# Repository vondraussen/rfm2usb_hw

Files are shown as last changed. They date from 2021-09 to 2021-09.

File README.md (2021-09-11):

# RFM2USB Hardware
USB to RFM69 board made with Kicad. Uses a STM32L151 microcontroller.
Firmware repo is [here](https://github.com/vondraussen/rfm2usb).

## Schematic
schematic
## Board



# Tools
```bash
pip install pcbdraw
```

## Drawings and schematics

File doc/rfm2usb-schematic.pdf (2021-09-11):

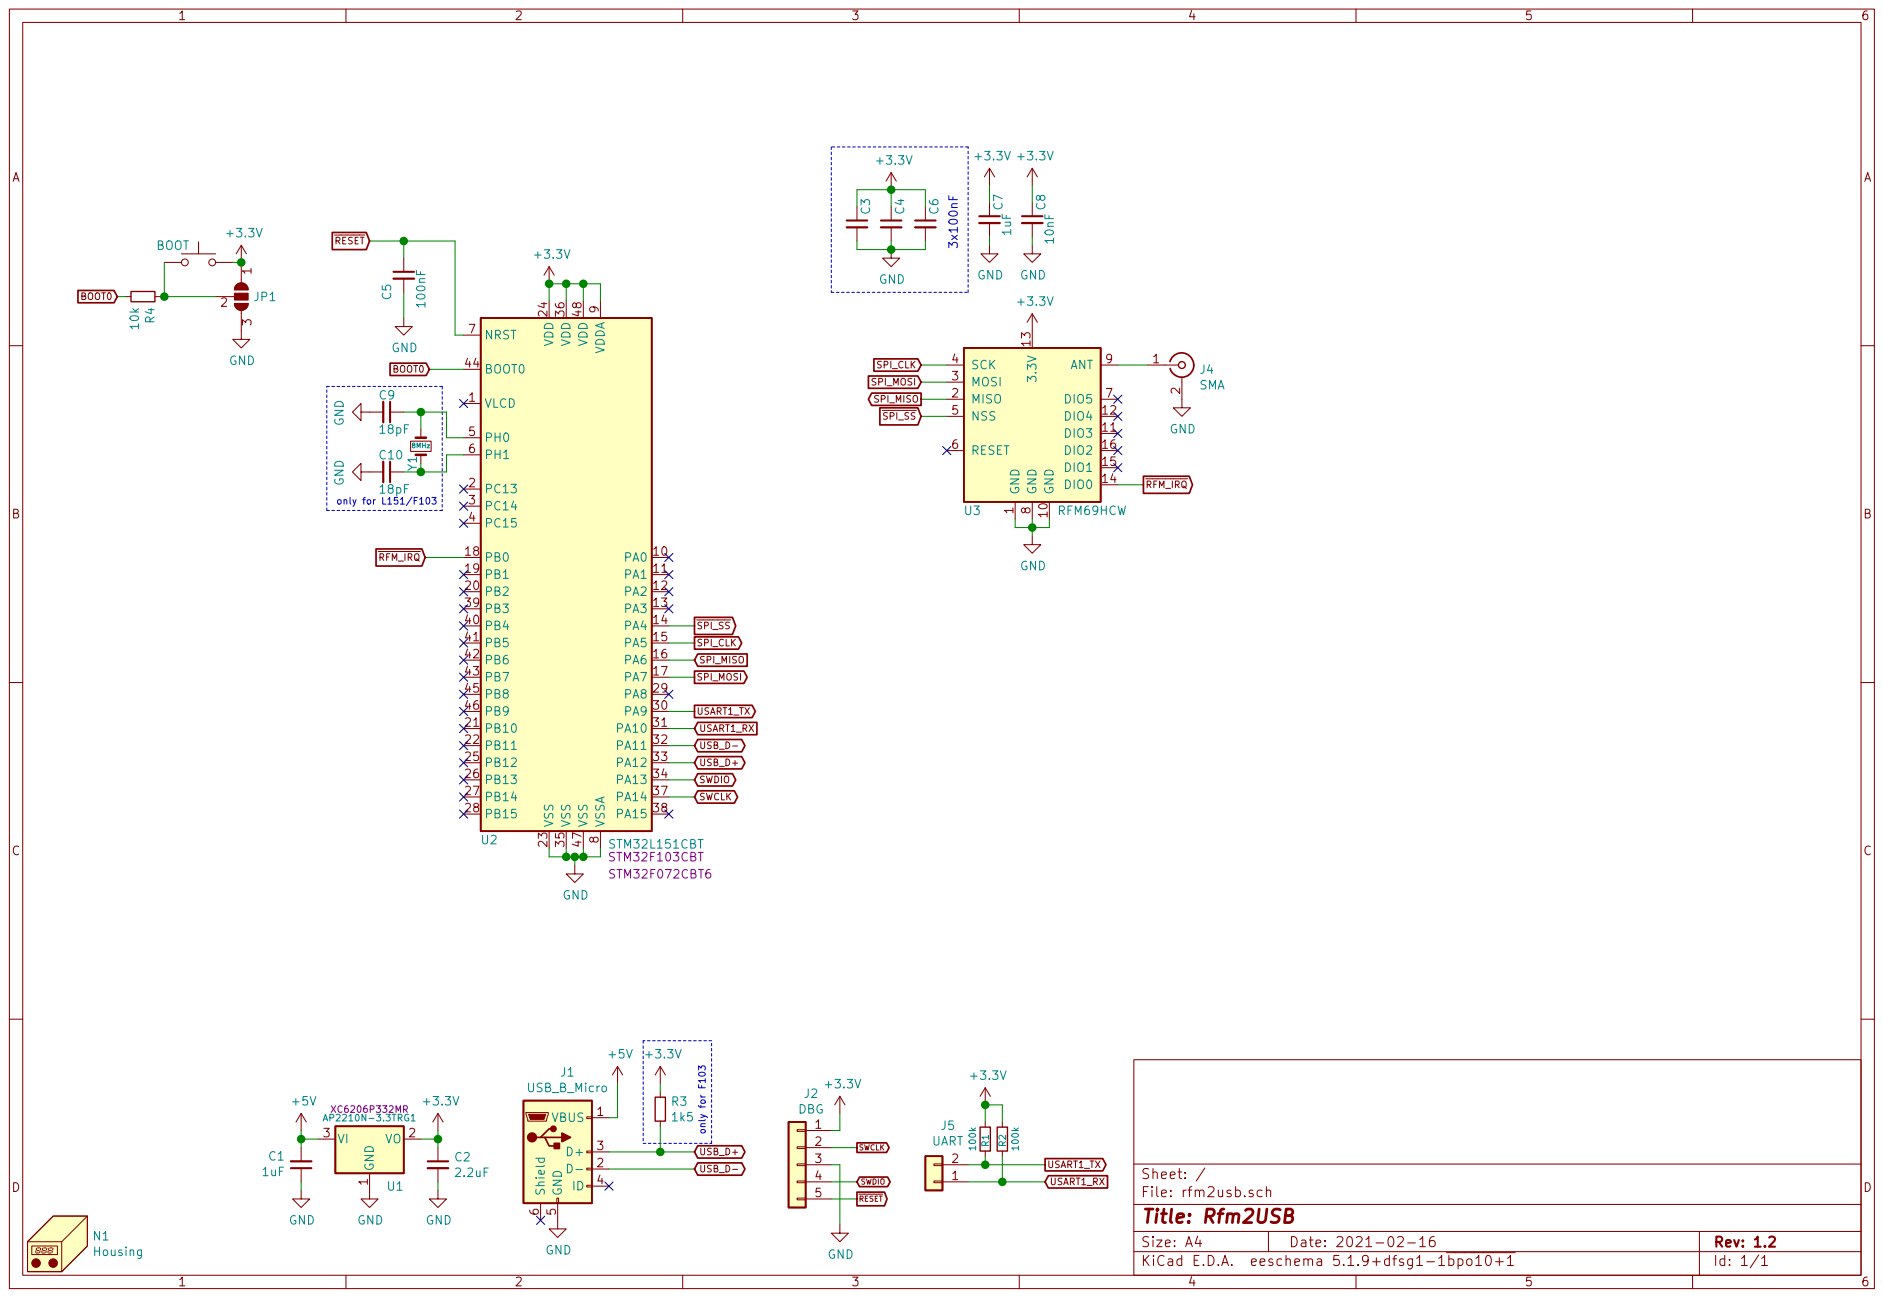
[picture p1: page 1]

9 VLCD 1 VSS 23 VSS 35 VSS 47 VSSA U2 8STM32L151CBT STM32F103CBT STM32F072CBT6 GND

1 GND 10 DIO3 11 DIO4 12 3.3V 13 DIO0 14 DIO1 15 DIO2 16 MISO 2 MOSI 3 SCK 4 NSS 5 RESET 6 DIO5 7 GND

File: rfm2usb.sch Sheet: / +3.3V GND

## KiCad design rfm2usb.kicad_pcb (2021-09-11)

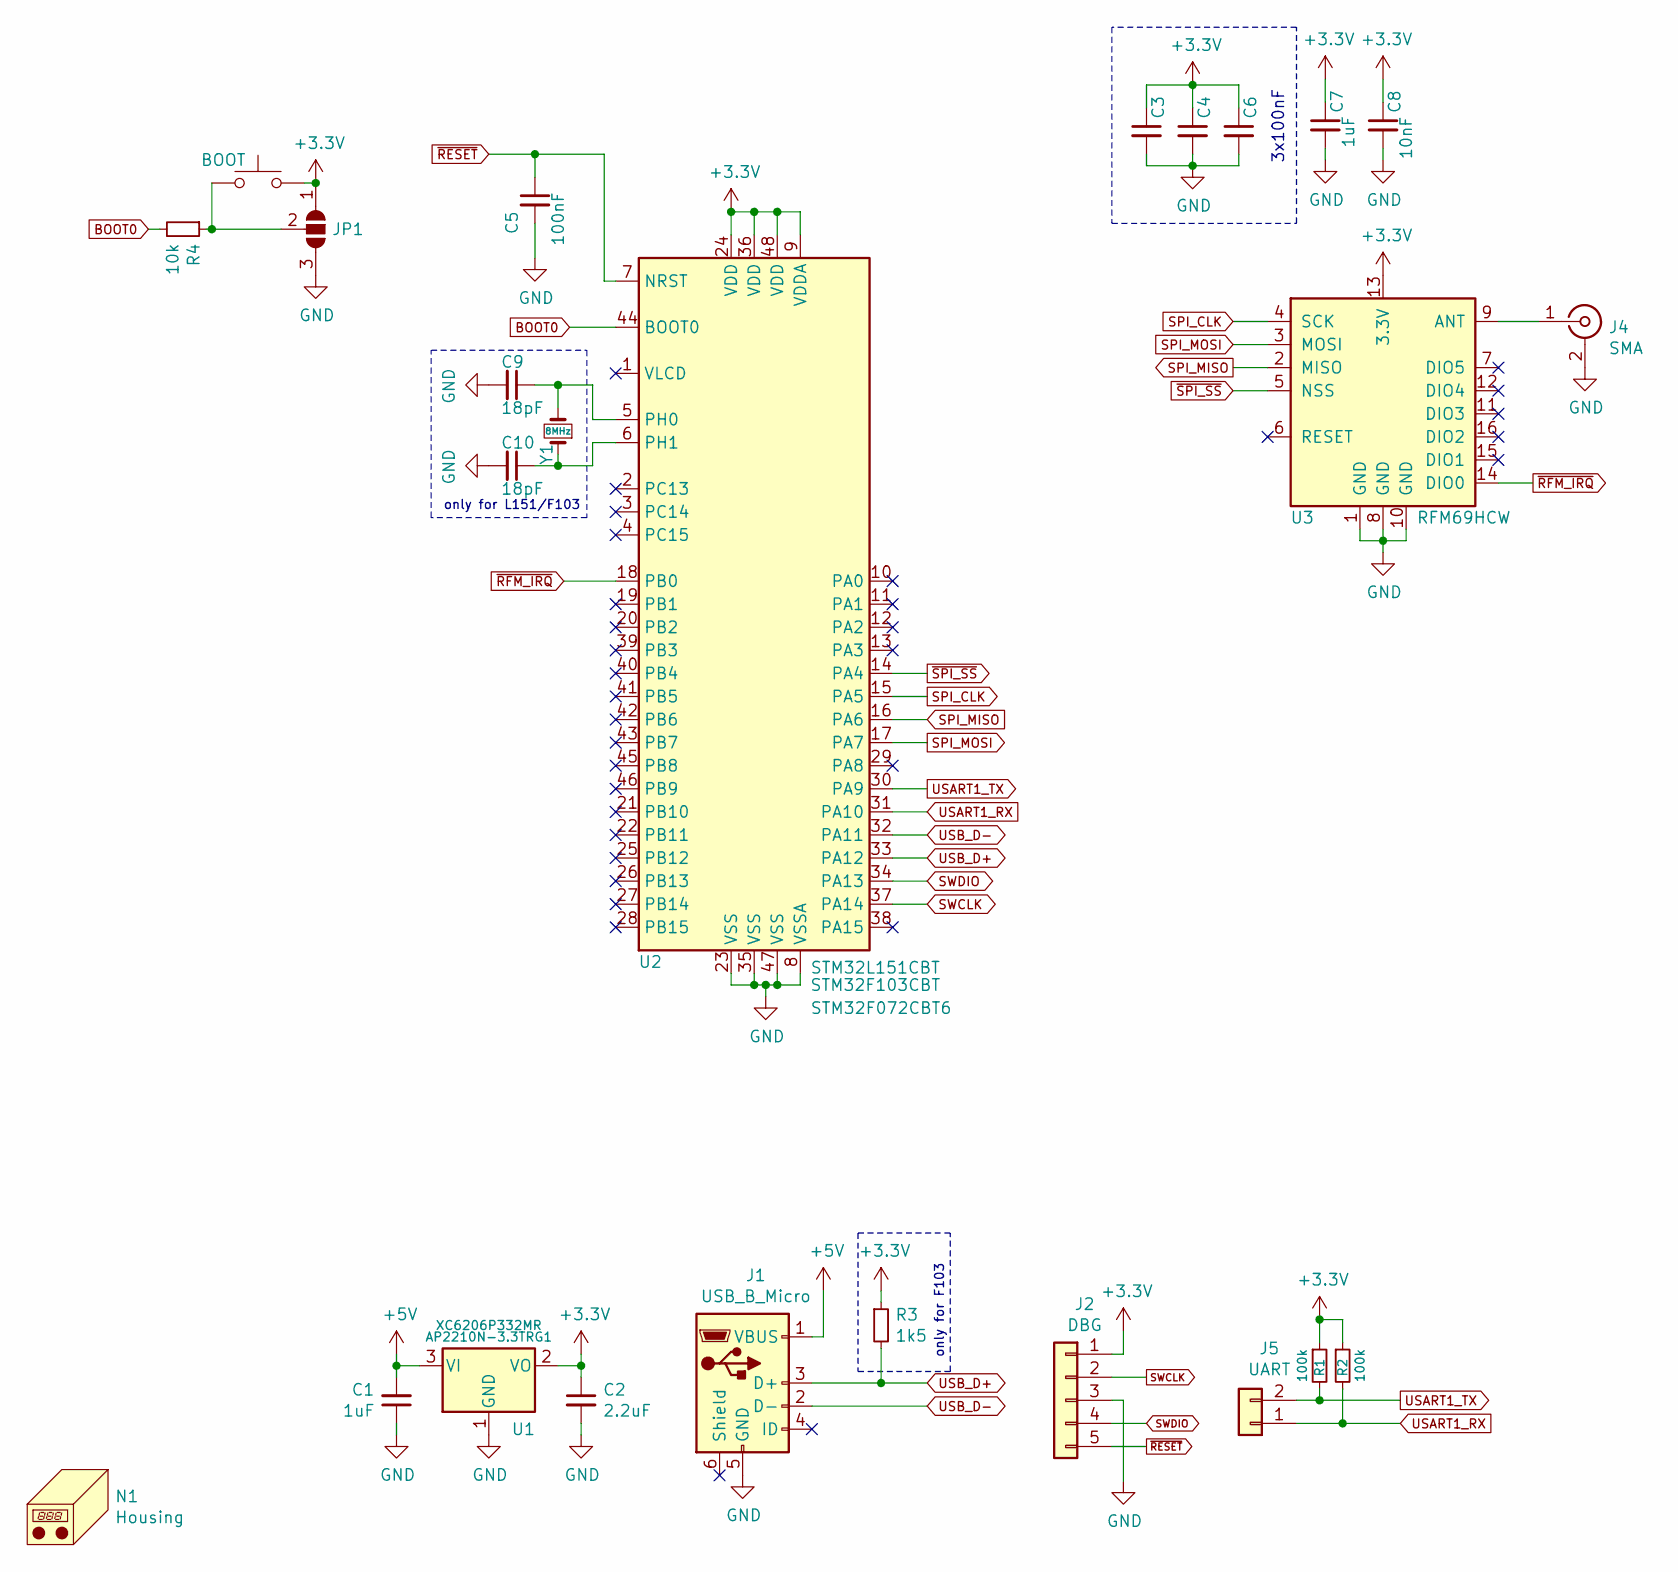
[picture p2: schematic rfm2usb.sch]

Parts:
BOOT1: BOOT; SW_Push_1P1T_NO_CK_KMR2; PART KMR241NG ULC LFS; Digikey CKN10285CT-ND‎
C1, C7: 1uF; C_0603_1608Metric
C2: 2.2uF; C_0603_1608Metric; Digikey 1276-1183-1-ND‎
C3, C4, C5, C6: 100nF; C_0603_1608Metric
C8: 10nF; C_0603_1608Metric
C9, C10: 18pF; C_0603_1608Metric; Digikey ‎1292-1494-1-ND‎
J1: USB_B_Micro; USB_Micro-B_Amphenol_10118194_Horizontal; Digikey ‎609-4618-1-ND‎
J2: DBG; PinHeader_1x05_P2.54mm_Vertical
J4: SMA; SMA_Molex_73251-1153_EdgeMount_Horizontal
J5: UART; PinHeader_1x02_P2.54mm_Vertical
JP1: SolderJumper_3_Open; SolderJumper-3_P1.3mm_Open_RoundedPad1.0x1.5mm_NumberLabels
N1: Housing; KiCad-Logo2_5mm_Copper
R1, R2: 100k; R_0603_1608Metric
R3: 1k5; R_0603_1608Metric
R4: 10k; R_0603_1608Metric
U1: AP2210N-3.3TRG1; SOT-23; Digikey AP2210N-3.3TRG1DICT-ND‎
U2: STM32L151CBT; LQFP-48_7x7mm_P0.5mm; Digikey 497-17516-1-ND‎
U3: RFM69HCW; HOPERF_RFM9XW_SMD
Y1: 8MHz; Crystal_SMD_3225-4Pin_3.2x2.5mm; Digikey ‎50-ECS-80-12-33Q-GN-CT-ND‎

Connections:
+3V3: BOOT1.2, C2.1, C3.1, C4.1, C6.1, C7.1, C8.1, J2.1, JP1.1 (A), R1.1, R2.1, R3.1, U1.2 (VO), U2.9 (VDDA), U2.24 (VDD), U2.36 (VDD), U2.48 (VDD), U3.13 (3.3V)
+5V: C1.2, J1.1 (VBUS), U1.3 (VI)
BOOT0: R4.2, U2.44 (BOOT0)
GND: C1.1, C2.2, C3.2, C4.2, C5.2, C6.2, C7.2, C8.2, C9.2, C10.2, J1.5 (GND), J2.3, J4.2 (Ext), JP1.3 (B), U1.1 (GND), U2.8 (VSSA), U2.23 (VSS), U2.35 (VSS), U2.47 (VSS), U3.1 (GND), U3.8 (GND), U3.10 (GND)
unnamed: BOOT1.1, JP1.2 (C), R4.1
unnamed: C9.1, U2.5 (PH0), Y1.2
unnamed: C10.1, U2.6 (PH1), Y1.1
unnamed: J4.1 (In), U3.9 (ANT)
SPI_CLK: U2.15 (PA5), U3.4 (SCK)
SPI_MISO: U2.16 (PA6), U3.2 (MISO)
SPI_MOSI: U2.17 (PA7), U3.3 (MOSI)
SWCLK: J2.2, U2.37 (PA14)
SWDIO: J2.4, U2.34 (PA13)
USART1_RX: J5.1, R2.2, U2.31 (PA10)
USART1_TX: J5.2, R1.2, U2.30 (PA9)
USB_D+: J1.3 (D+), R3.2, U2.33 (PA12)
USB_D-: J1.2 (D-), U2.32 (PA11)
~RESET: C5.1, J2.5, U2.7 (NRST)
~RFM_IRQ: U2.18 (PB0), U3.14 (DIO0)
~SPI_SS: U2.14 (PA4), U3.5 (NSS)

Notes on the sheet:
3x100nF
only for L151/F103
only for F103

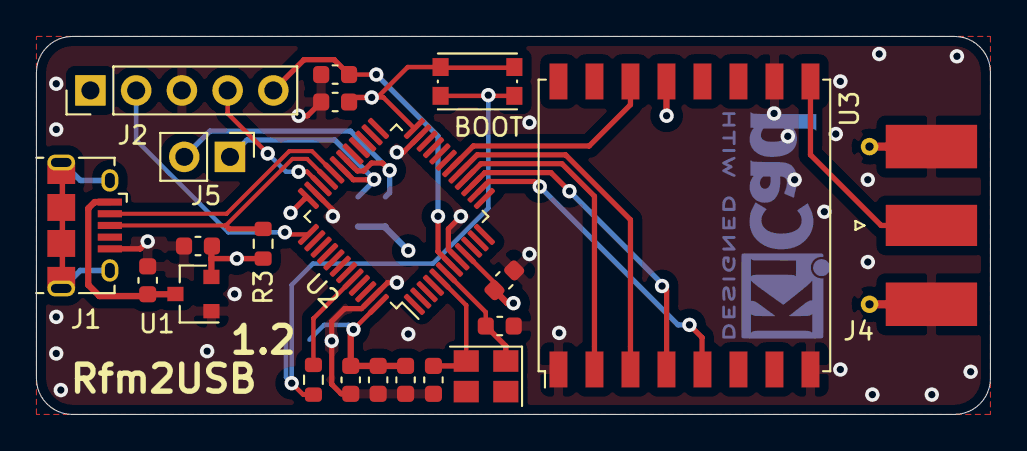
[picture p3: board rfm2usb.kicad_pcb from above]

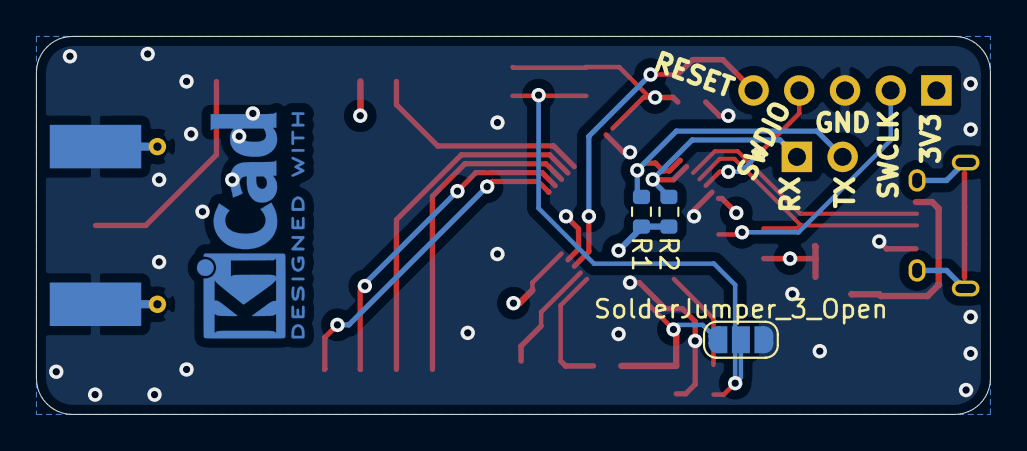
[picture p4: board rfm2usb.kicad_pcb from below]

Board: 4 copper layers, 53.0 x 21.0 mm, 25 parts (4 on the bottom side), 20 nets.

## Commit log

2021-02-18 init commit
    [rfm2usb.kicad_pcb, rfm2usb.sch]
2021-02-18 add gerber export action
2021-03-06 change stm32 footprint
    [rfm2usb.kicad_pcb, rfm2usb.sch]
2021-03-06 fix clearance false pos
    [rfm2usb.kicad_pcb]
2021-09-11 use svg for board pics
2021-09-11 replace reset button with boot button this is more useful
    [rfm2usb.kicad_pcb, rfm2usb.sch]
